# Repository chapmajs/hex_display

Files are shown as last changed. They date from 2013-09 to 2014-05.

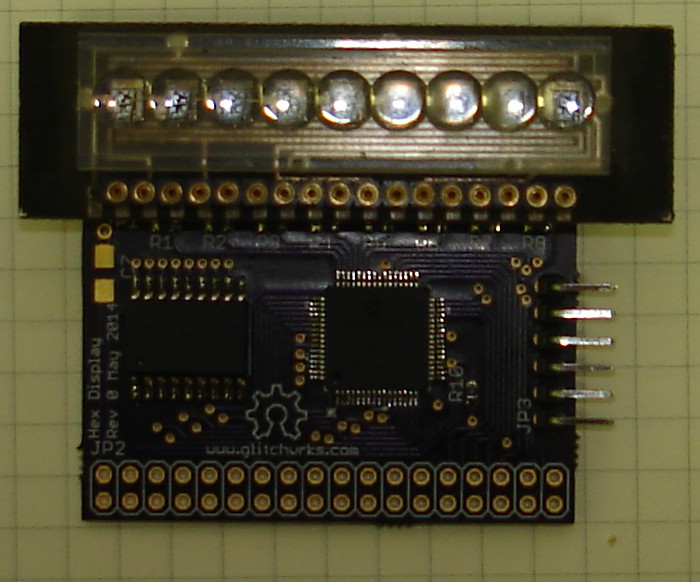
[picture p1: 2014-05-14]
rev0.jpg

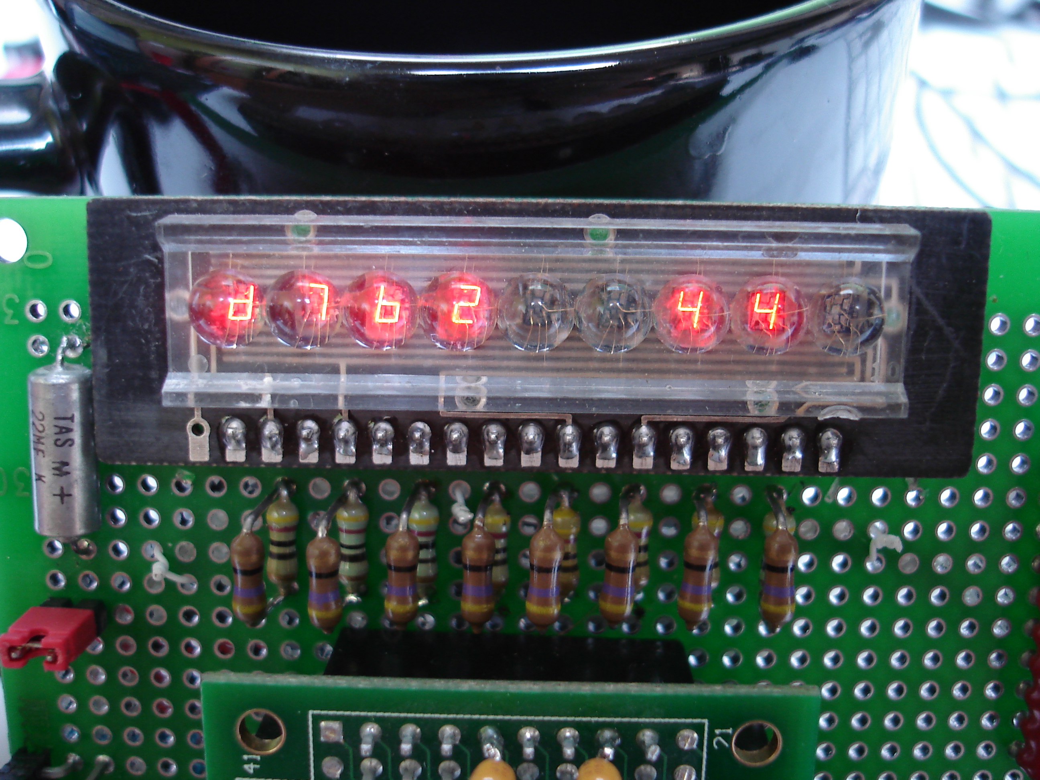
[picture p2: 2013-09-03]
display.jpg

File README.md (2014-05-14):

PIC Based Mutiplexed 7-segment LED Display
==========================================

A project to drive multiplexed 7-segment LED displays as hex displays using a Microchip PIC18F6310 with a minimum of external components. This is a work in progress!

This project is released as [Open Source Hardware (OSHW)](http://freedomdefined.org/OSHW). All hardware contained within this repository are covered by a [Creative Commons Attribution-ShareAlike 3.0 license (CC BY-SA 3.0)](http://creativecommons.org/licenses/by-sa/3.0/). Firmware and software are licensed under GPLv3 -- see LICENSE and GPL-3.0 for more information.

### Current Status

Rev 0 PC board has been tested, sample firmware in this repository displays 'deadbeef'. Minor tweaks to the PC board layout are required for 0.1" perfboard compatibility. 24-bit port input has not yet been tested.

### Why?

"Intelligent" single-nybble hexadecimal displays like the TIL311 are available, as well as 7-segment hex decoders; however, these devices are no longer in production and they're expensive, when you can find them. The 7-segment hex decoders that are currently available handle single displays only and don't work with multi-character multiplexed displays.

### How?

This display project implements a multi-character bitmapped display using an interrupt-driven subroutine to handle multiplexing. A display buffer is used to simplify loading data for display. Character selection was delegated to a subroutine that enables the appropriate cathode driver pin based on an offset. This allows the size of the display to be changed with minimal firmware modification.

A PIC microcontroller with plenty of I/O was chosen to allow input of 24 bits of binary data in parallel (16 bit address + 8 bit data, a common arrangement with old 8-bit processors like the Intel 8080/8085, Zilog Z80, or MOS 6502). Using this device as a debugging tool was the primary goal; however, it was designed in such a way that the PIC's onboard devices can also act as data sources for the display. It's possible to display data from I2C, SPI, RS-232, parallel port, or ADC sources. Additionally, one could drive dot matrix displays with the same firmware.

An in-memory lookup table provides translation from single hex nybbles to appropriate bitmap patterns for 7-segment displays. A routine utilizing this table can be called from firmware to produce hex digits if bitmap characters are not desired.

### Who?

[The Glitch Works](http://www.glitchwrks.com/)

There's a thread on the [BinRev Forums](http://www.binrev.com/forums/index.php/topic/46160-hex-display-project/) for discussion

### Files

* display.asm: PIC18F6310 firmware for driving mutiplexed common cathode 7-segment displays
* pinouts.md: PC board connector pinouts
* schematic.sch: Eagle CAD schematic
* schematic.brd: Eagle CAD board layout
* eagle_libs: Directory containing nonstandard Eagle CAD parts

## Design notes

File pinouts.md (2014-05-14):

Hex Display rev 0 Pinouts
-------------------------

### JP1 -- LED display module

JP1 pinouts correspond with 8/9 digit magnified 7-segment display modules I have on hand. Cathode 0 is not driven since the first digit is unpopulated on 8 digit displays. Segments map in order to Port B on the PIC.

```
1     NC
2     common cathode 0 (not driven)
3     segment C
4     common cathode 1
5     decimal point
6     common cathode 2
7     segment A
8     common cathode 3
9     segment E
10    common cathode 4
11    segment D
12    common cathode 5
13    segment G
14    common cathode 6
15    segment B
16    common cathode 7
17    segment F
18    common cathode 8
```

### PORTB -- Segment Control Port

```
RB0   segment C
RB1   decimal point
RB2   segment A
RB3   segment E
RB4   segment D
RB5   segment G
RB6   segment B
RB7   segment F
```

### Cathode Control Pins

Cathode control pins drive common cathodes through a ULN2803 octal NPN Darlington array.

```
RA6   common cathode 1
RA7   common cathode 2
RG4   common cathode 3
RG3   common cathode 4
RE6   common cathode 5
RE5   common cathode 6
RE4   common cathode 7
RE3   common cathode 8
```

### JP2 -- Application Connector

The application connector provides PIC ports C, D, and F as well as RE0, RE1, and RE2. Power and ground pins are provided as well.

```
Vcc      1   o o    2     Vcc
RD0      3   o o    4     RD1
RD2      5   o o    6     RD3
RD4      7   o o    8     RD5
RD6      9   o o   10     RD7
RE2     11   o o   12     NC
RE0     13   o o   14     RE1
RF0     15   o o   16     RF1
RF2     17   o o   18     RF3
RF4     19   o o   20     RF5
RF6     21   o o   22     RF7
NC      23   o o   24     NC
NC      25   o o   26     NC
RC0     27   o o   28     RC1
RC2     29   o o   30     RC3
RC4     31   o o   32     RC5
RC6     33   o o   34     RC7
GND     35   o o   36     GND
```

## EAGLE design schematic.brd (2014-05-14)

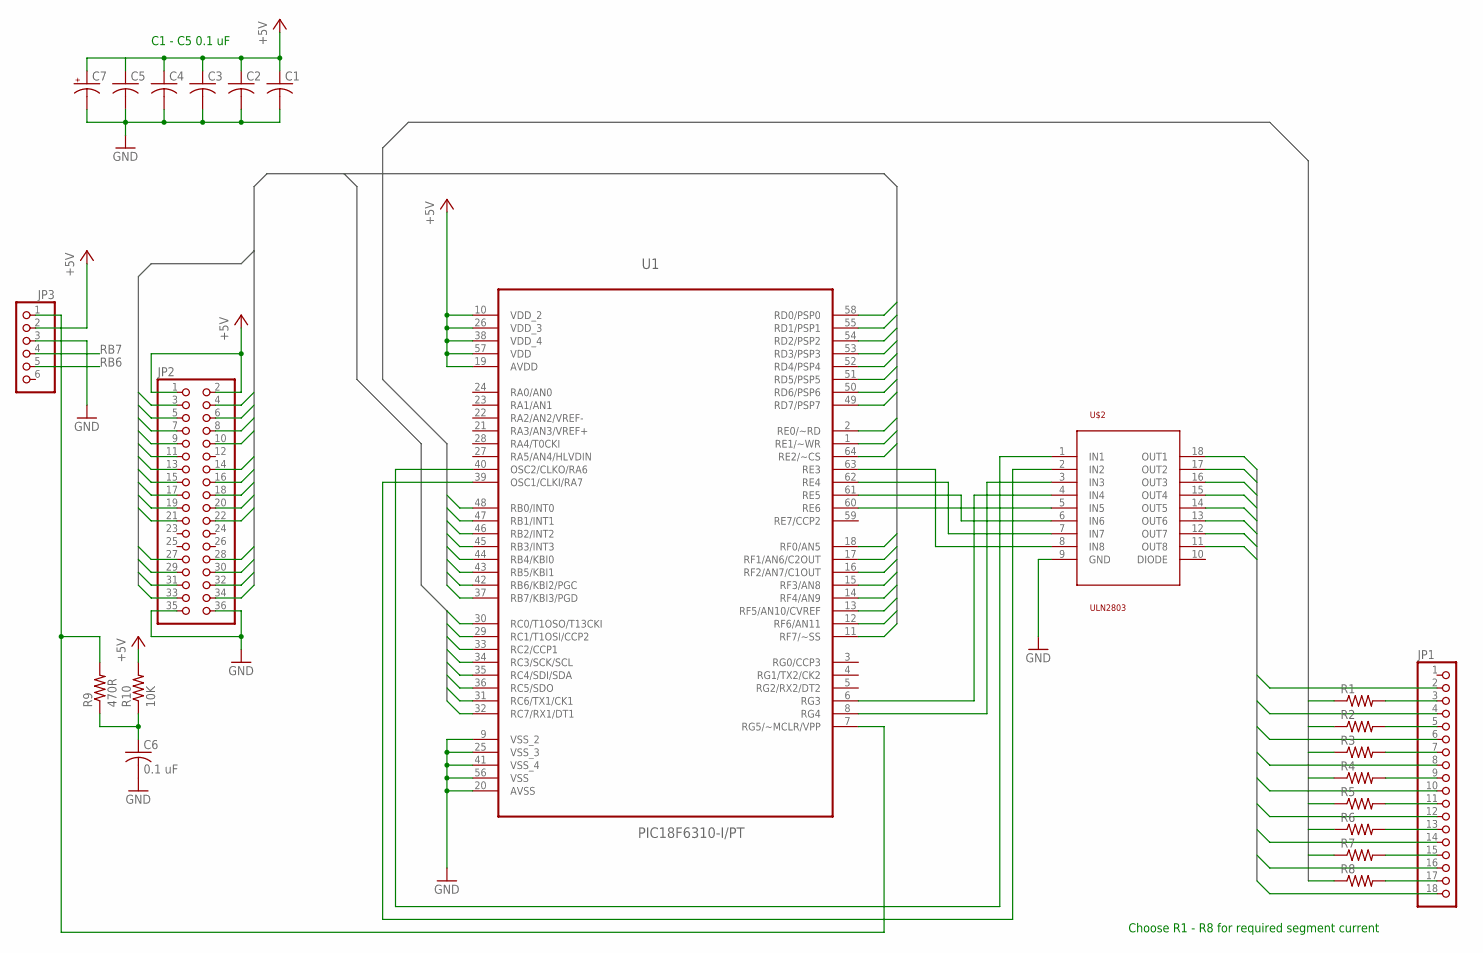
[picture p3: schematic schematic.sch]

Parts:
C1, C2, C3, C4, C5: C-USC0603K; C0603K
C6: 0.1 uF; C0603K
C7: CPOL-USB/3528-21W; B/3528-21W
JP1: PINHD-1X18; 1X18
JP2: PINHD-2X18; 2X18
JP3: PINHD-1X6; 1X06
R1, R2, R3, R4, R5, R6, R7, R8: R-US_R0603; R0603
R9: 470R; R0603
R10: 10K; R0603
U1: PIC18F6310-I/PT; QFP50P1200X1200X120-64N
U$2: ULN2803; SO18L

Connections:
+5V: C1.1, C2.1, C3.1, C4.1, C5.1, C7.+, JP2.1, JP2.2, JP3.2, R10.2, U1.10 (VDD_2), U1.19 (AVDD), U1.26 (VDD_3), U1.38 (VDD_4), U1.57 (VDD)
DIGIT0: JP1.2
DIGIT1: JP1.4, U$2.18 (OUT1)
DIGIT2: JP1.6, U$2.17 (OUT2)
DIGIT3: JP1.8, U$2.16 (OUT3)
DIGIT4: JP1.10, U$2.15 (OUT4)
DIGIT5: JP1.12, U$2.14 (OUT5)
DIGIT6: JP1.14, U$2.13 (OUT6)
DIGIT7: JP1.16, U$2.12 (OUT7)
DIGIT8: JP1.18, U$2.11 (OUT8)
GND: C1.2, C2.2, C3.2, C4.2, C5.2, C6.2, C7.-, JP2.35, JP2.36, JP3.3, U1.9 (VSS_2), U1.20 (AVSS), U1.25 (VSS_3), U1.41 (VSS_4), U1.56 (VSS), U$2.9 (GND)
unnamed: U1.63 (RE3), U$2.8 (IN8)
unnamed: U1.62 (RE4), U$2.7 (IN7)
unnamed: U1.61 (RE5), U$2.6 (IN6)
unnamed: U1.60 (RE6), U$2.5 (IN5)
unnamed: U1.40 (OSC2/CLKO/RA6), U$2.1 (IN1)
unnamed: U1.39 (OSC1/CLKI/RA7), U$2.2 (IN2)
unnamed: U1.6 (RG3), U$2.4 (IN4)
unnamed: U1.8 (RG4), U$2.3 (IN3)
unnamed: JP3.1, R9.2, U1.7 (RG5/~MCLR/VPP)
unnamed: JP1.3, R1.2
unnamed: JP1.5, R2.2
unnamed: JP1.7, R3.2
unnamed: JP1.9, R4.2
unnamed: JP1.11, R5.2
unnamed: C6.1, R9.1, R10.1
unnamed: JP1.13, R6.2
unnamed: JP1.15, R7.2
unnamed: JP1.17, R8.2
RB0: R1.1, U1.48 (RB0/INT0)
RB1: R2.1, U1.47 (RB1/INT1)
RB2: R3.1, U1.46 (RB2/INT2)
RB3: R4.1, U1.45 (RB3/INT3)
RB4: R5.1, U1.44 (RB4/KBI0)
RB5: R6.1, U1.43 (RB5/KBI1)
RB6: JP3.5, R7.1, U1.42 (RB6/KBI2/PGC)
RB7: JP3.4, R8.1, U1.37 (RB7/KBI3/PGD)
RC0: JP2.27, U1.30 (RC0/T1OSO/T13CKI)
RC1: JP2.28, U1.29 (RC1/T1OSI/CCP2)
RC2: JP2.29, U1.33 (RC2/CCP1)
RC3: JP2.30, U1.34 (RC3/SCK/SCL)
RC4: JP2.31, U1.35 (RC4/SDI/SDA)
RC5: JP2.32, U1.36 (RC5/SDO)
RC6: JP2.33, U1.31 (RC6/TX1/CK1)
RC7: JP2.34, U1.32 (RC7/RX1/DT1)
RD0: JP2.3, U1.58 (RD0/PSP0)
RD1: JP2.4, U1.55 (RD1/PSP1)
RD2: JP2.5, U1.54 (RD2/PSP2)
RD3: JP2.6, U1.53 (RD3/PSP3)
RD4: JP2.7, U1.52 (RD4/PSP4)
RD5: JP2.8, U1.51 (RD5/PSP5)
RD6: JP2.9, U1.50 (RD6/PSP6)
RD7: JP2.10, U1.49 (RD7/PSP7)
RE0: JP2.13, U1.2 (RE0/~RD)
RE1: JP2.14, U1.1 (RE1/~WR)
RE2: JP2.11, U1.64 (RE2/~CS)
RF0: JP2.15, U1.18 (RF0/AN5)
RF1: JP2.16, U1.17 (RF1/AN6/C2OUT)
RF2: JP2.17, U1.16 (RF2/AN7/C1OUT)
RF3: JP2.18, U1.15 (RF3/AN8)
RF4: JP2.19, U1.14 (RF4/AN9)
RF5: JP2.20, U1.13 (RF5/AN10/CVREF)
RF6: JP2.21, U1.12 (RF6/AN11)
RF7: JP2.22, U1.11 (RF7/~SS)

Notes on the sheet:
C1 - C5 0.1 uF
Choose R1 - R8 for required segment current

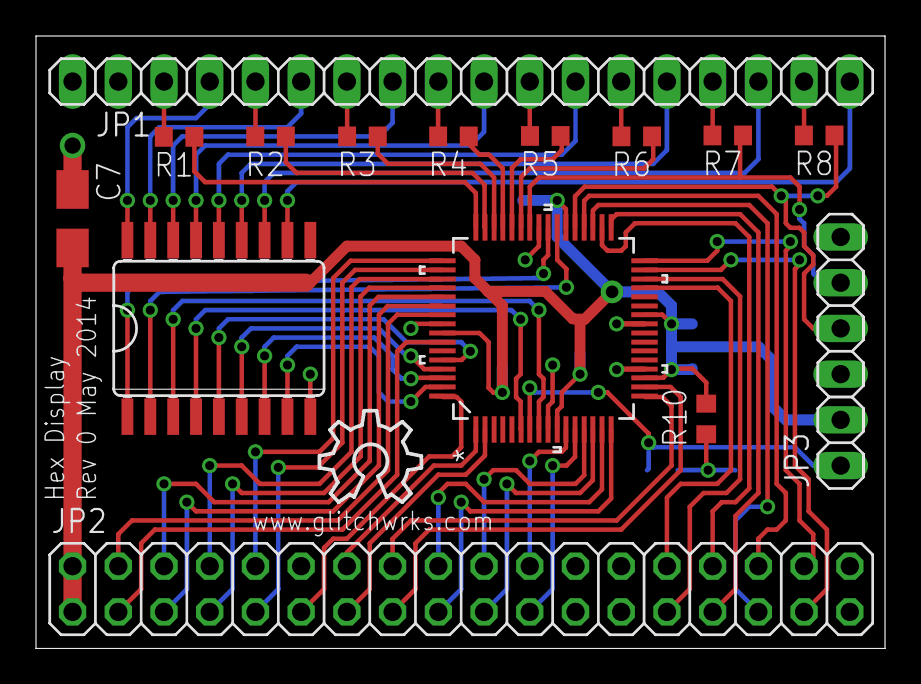
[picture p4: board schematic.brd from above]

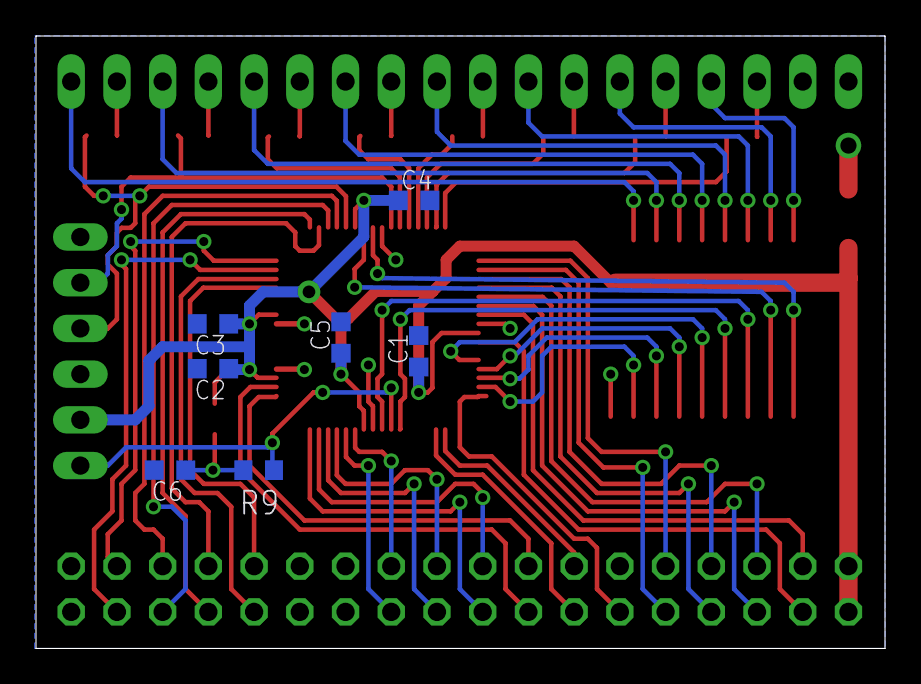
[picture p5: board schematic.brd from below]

Board: 2 copper layers, 47.2 x 34.0 mm, 23 parts (7 on the bottom side), 63 nets.

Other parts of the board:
U$1: OSHW_8X200_NOTEXT

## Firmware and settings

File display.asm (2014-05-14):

; PIC18F6310 based LED hex display
; Version 0.1.1 Copyright (c) 2014 Jonathan Chapman
; http://www.glitchwrks.com
;
; See LICENSE included in the project root for licensing information.

; PIC18F6310 Configuration Bit Settings
    #include <p18f6310.inc>

    CONFIG  WDT = OFF           ; Watchdog Timer disabled
    CONFIG  CP = OFF            ; Code Protect disabled
    CONFIG  MCLRE = ON          ; Master Clear Enable
    CONFIG  OSC = INTIO67       ; Internal oscillator block, port function on RA6 and RA7
    CONFIG  IESO = OFF          ; Oscillator Switchover mode disabled

    ORG 0
    goto Start

    ORG 8
    goto ISR

; Variable declarations
    cblock  0x20
        Current                 ; Current active digit
        chars:8                 ; Display buffer
        W_temp                  ; Temporary storage for ISR
        S_temp
    endc

DIGITS  EQU     d'8'

Start:
        ; Set up the internal oscillator
        movlw   B'11100010'
        movwf   OSCCON
        movlw   B'11100000'
        movwf   INTCON

        ; Set the ports required for display output to outputs
        clrf    TRISB
        clrf    TRISA
        clrf    TRISE
        clrf    TRISG

        ; Set the initial current digit to 0
        clrf    Current

        ; Fill the display buffer with test data
        movlw   0x0D
        call    HEX
        movwf   chars + d'0'
        movlw   0x0E
        call    HEX
        movwf   chars + d'1'
        movlw   0x0A
        call    HEX
        movwf   chars + d'2'
        movlw   0x0D
        call    HEX
        movwf   chars + d'3'
        movlw   0x0B
        call    HEX
        movwf   chars + d'4'
        movlw   0x0E
        call    HEX
        movwf   chars + d'5'
        movlw   0x0E
        call    HEX
        movwf   chars + d'6'
        movlw   0x0F
        call    HEX
        movwf   chars + d'7'

        ; Preload TIMER0 with the multiplex frequency and go
        movlw   B'10001000'
        movwf   T0CON
        movlw   B'11111100'
        movwf   TMR0H
        clrf    TMR0L
NOPPER: nop
        goto    NOPPER              ; Spin in a loop while the ISR works

;;;;;;;;;;;;;;;;;;;;;;;;;;;;;;;;;;;;;;;;;;;;;;;;;;;;;;;;;;;;;;;;;;;;;;;;;;;;;;;;
; ISR -- Interrupt Service Routine
;
; This routine handles multiplexing under the control of TIMER0. Data is moved
; from the current element of the display buffer onto PORTB after the previous
; digit is switched off. The current digit is then turned on and TIMER0 is
; reset.
;
; pre:  Digit blanking masks are specified in this subroutine
; post: All digits are turned off
;;;;;;;;;;;;;;;;;;;;;;;;;;;;;;;;;;;;;;;;;;;;;;;;;;;;;;;;;;;;;;;;;;;;;;;;;;;;;;;;
ISR:    movwf   W_temp              ; Save W, S
        movf    STATUS, W
        movwf   S_temp
        clrf    FSR0H
        movlw   chars + d'0'        ; Get the position of the current character
        addwf   Current, W          ; to be displayed
        movwf   FSR0L
        call    BLANK
        movf    INDF0, W
        movwf   PORTB
        movf    Current, W
        call    DIGIT
        movf    Current, W
        xorlw   DIGITS              ; Have we reached the last display char?
        btfsc   STATUS, Z
        goto    ISR1                ; Yes, reset the current character
        incf    Current, f          ; No, increment the current character
        goto    ISR2
ISR1:   clrf    Current
ISR2:   movlw   B'11111100'         ; Reset TIMER0
        movwf   TMR0H
        clrf    TMR0L
        movf    W_temp, W           ; Restore W, S
        movf    S_temp, W
        movwf   STATUS
        bcf     INTCON, 2           ; Turn interrupts on and return
        retfie

;;;;;;;;;;;;;;;;;;;;;;;;;;;;;;;;;;;;;;;;;;;;;;;;;;;;;;;;;;;;;;;;;;;;;;;;;;;;;;;;
; BLANK -- Blank the display
;
; pre:  Digit blanking masks are specified in this subroutine
; post: All digits are turned off
;;;;;;;;;;;;;;;;;;;;;;;;;;;;;;;;;;;;;;;;;;;;;;;;;;;;;;;;;;;;;;;;;;;;;;;;;;;;;;;;
BLANK:  movlw   B'10000111'
        andwf   PORTE, f
        movlw   B'00111111'
        andwf   PORTA, f
        movlw   B'11100111'
        andwf   PORTG, f
        return

;;;;;;;;;;;;;;;;;;;;;;;;;;;;;;;;;;;;;;;;;;;;;;;;;;;;;;;;;;;;;;;;;;;;;;;;;;;;;;;;
; DIGIT -- Turn on the control line for a digit
;
; pre:  W register contains the number of the digit to turn on
;       Digit control bits are defined in this subroutine
;       All other digits are currently turned off
; post: The bit associated with the digit specified by W is set
;;;;;;;;;;;;;;;;;;;;;;;;;;;;;;;;;;;;;;;;;;;;;;;;;;;;;;;;;;;;;;;;;;;;;;;;;;;;;;;;
DIGIT:  mullw   d'4'
        movf    PRODL, W
        addwf   PCL, f
        bsf     PORTA, 6
        return
        bsf     PORTA, 7
        return
        bsf     PORTG, 4
        return
        bsf     PORTG, 3
        return
        bsf     PORTE, 6
        return
        bsf     PORTE, 5
        return
        bsf     PORTE, 4
        return
        bsf     PORTE, 3
        return

;;;;;;;;;;;;;;;;;;;;;;;;;;;;;;;;;;;;;;;;;;;;;;;;;;;;;;;;;;;;;;;;;;;;;;;;;;;;;;;;
; HEX -- Convert a Nybble to its 7-segment bit pattern
;
; pre:  W register contains masked nybble to convert
;       Bitmap table exists at 0x0400
; post: W contains 7-segment bitmap
;;;;;;;;;;;;;;;;;;;;;;;;;;;;;;;;;;;;;;;;;;;;;;;;;;;;;;;;;;;;;;;;;;;;;;;;;;;;;;;;
HEX:    movwf   TBLPTRL
        movlw   0x00
        movwf   TBLPTRU
        movlw   0x04
        movwf   TBLPTRH
        tblrd*
        movf    TABLAT, W
        return

        org 0x0400
        db  B'11011101', B'01000001', B'01111100', B'01110101'
        db  B'11100001', B'10110101', B'10111101', B'01000101'
        db  B'11111101', B'11110101', B'11101101', B'10111001'
        db  B'10011100', B'01111001', B'10111100', B'10101100'

    end

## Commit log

2014-05-01 Adding rev 0 schematic and board
    [schematic.brd, schematic.sch]
2014-05-01 Adding board/schematic to README
2014-05-14 Adding comments, cleanup, updating for rev 0 PC board
2014-05-14 Adding pinouts for rev 0 board
2014-05-14 Updating schematic, board
    [schematic.brd, schematic.sch]
2014-05-14 Adding rev0 board image
